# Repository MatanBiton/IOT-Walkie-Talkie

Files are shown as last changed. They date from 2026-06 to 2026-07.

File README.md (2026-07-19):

# Walkie-Talkie Project — Group 14
Group members: Erel Hadad, Sapir Kvetny, Matan Biton  

Advisors: Rami Abu Much, Tom Sofer
## Details about the project

A half-duplex ESP32 walkie-talkie with channel selection through an OLED interface. Audio is transmitted through Firebase Realtime Database in **VoIP mode** and can fall back to **ESP-NOW P2P mode** after repeated upload failures. The system also provides user-availability checks, adjustable audio settings, communication-status feedback, and a companion Flutter application.

Before flashing each ESP32, configure its unique `DEVICE_ID` and `USER_ID`, Wi-Fi settings, and Firebase RTDB URL in `ESP32/app_config.h`.

## Folder description

* `ESP32/`: ESP32 firmware source code.
* `Documentation/`: wiring diagram, Fritzing connection diagram file and basic operating instructions.
* `Unit Tests/`: tests for individual input and output hardware components.
* `assets/`: project poster.

## ESP32 SDK version used in this project

* **ESP32 Arduino Core by Espressif Systems:** `2.0.17`

## Arduino/ESP32 libraries used in this project

* **FirebaseClient by Mobizt** — version **2.2.13** or a compatible 2.2.x release.
* **ESP_SSLClient** — **3.1.3**.
* **Adafruit GFX Library** — **1.12.6**.
* **Adafruit SSD1306** — **2.5.17**.
* **WiFi, Wire, ESP-NOW, I2S, FreeRTOS and mbedTLS** — included with the ESP32 Arduino Core.

## Hardware list

Quantities below are for **one Walkie-Talkie device**.

|  Quantity | Component | Purpose |
| ---: | --- | --- |
| 1 | ESP32 development board | Main controller, Wi-Fi and ESP-NOW communication |
| 1 | INMP441 I2S microphone | Captures voice input |
| 1 | max98357 audio DAC amplifier | Drives the speaker |
| 1 | Speaker | Plays received audio |
| 1 | 128×64 SSD1306 I2C OLED display | Displays channels, status, settings and statistics |
| 3 | Momentary push buttons | PTT, left navigation and right navigation |
| 1 | LED | Indicates recording and pending communication work |
| 1 | LED current-limiting resistor | Protects the status LED |
| 1 | USB cable and suitable USB power source | Programs and powers the ESP32 |
| As needed | Breadboard, perfboard or custom mounting board | Holds and connects the components |
| As needed | Jumper wires / hookup wire | Electrical connections |
| 1 set | 3D-printed enclosure parts | Houses the completed device |

## Connection diagram

| Component | ESP32 connection |
| --- | --- |
| I2S speaker | LRC/WS: GPIO 12, BCLK: GPIO 14, DIN: GPIO 27 |
| I2S microphone  | SD: GPIO 34, SCK/BCLK: GPIO 32, WS: GPIO 33  |
| Main PTT button | GPIO 25 to physical GND |
| Left button | Input: GPIO 4, virtual GND: GPIO 15 |
| Right button | Input: GPIO 19, virtual GND: GPIO 5 |
| SSD1306 OLED | SCL: GPIO 22, SDA: GPIO 23 |
| Status LED | GPIO 26 through a current-limiting resistor  |

The buttons use `INPUT_PULLUP`, so a pressed button reads `LOW`. GPIO 15 and GPIO 5 are configured as outputs and held `LOW` to act as virtual grounds.

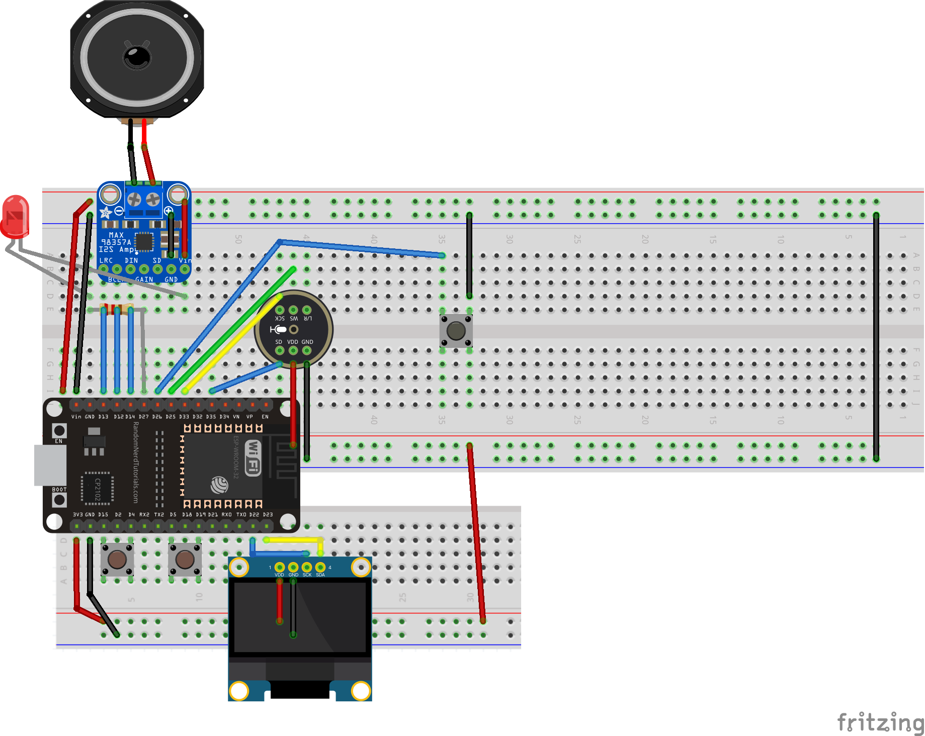
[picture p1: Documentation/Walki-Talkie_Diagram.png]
Connection diagram


## Project Poster

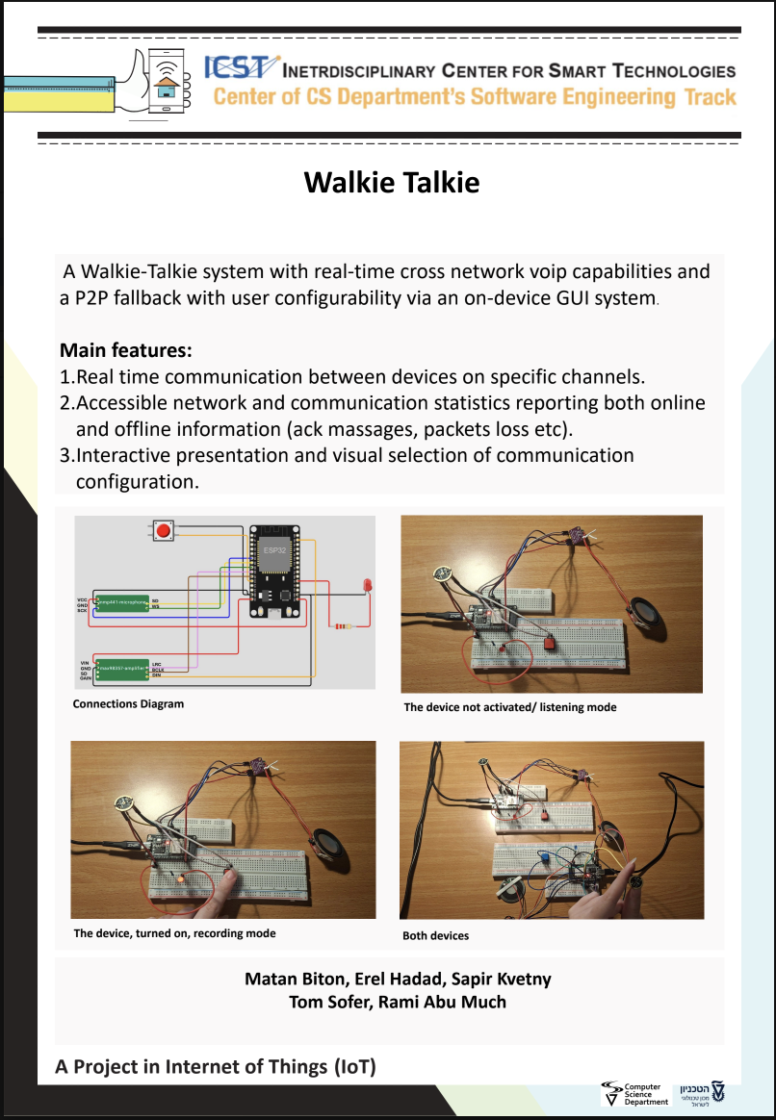
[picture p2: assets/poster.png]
Project poster


---

This project is part of [ICST — The Interdisciplinary Center for Smart Technologies](https://icst.cs.technion.ac.il/), Taub Faculty of Computer Science, Technion.

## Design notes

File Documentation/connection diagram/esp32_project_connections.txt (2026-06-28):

ESP32 Project Hardware Connections
===================================

Current existing connections should remain unchanged.

1. Existing Main Button
-----------------------
ESP32 GPIO14 -> button -> GND

Code note:
- Configure GPIO14 as INPUT_PULLUP.
- Button is active-low:
  pressed = LOW
  released = HIGH

2. Recording LED
----------------
ESP32 GPIO4 -> resistor -> long LED leg / anode
short LED leg / cathode -> GND

Code note:
- Configure GPIO4 as OUTPUT.

3. I2S Microphone
-----------------
Mic VCC / VDD  -> ESP32 3.3V
Mic GND        -> ESP32 GND
Mic SCK / BCLK -> ESP32 GPIO32
Mic WS / LRCLK -> ESP32 GPIO25
Mic SD / DOUT  -> ESP32 GPIO33

4. I2S Speaker Amplifier
------------------------
ESP32 GPIO27 -> amplifier BCLK / BCK
ESP32 GPIO26 -> amplifier LRC / WS
ESP32 GPIO22 -> amplifier DIN / DATA
ESP32 GND    -> amplifier GND
ESP32 5V/VIN -> amplifier VIN / VCC

5. OLED Display - 0.96 inch 128x64 SSD1306
------------------------------------------
Assumed interface: I2C, 4-pin OLED module.

OLED VCC -> ESP32 3.3V
OLED GND -> ESP32 GND
OLED SDA -> ESP32 GPIO21
OLED SCL -> ESP32 GPIO19

6. GUI Button 1 (Left)
--------------------------
ESP32 GPIO18 -> button -> GND

Code note:
- Configure GPIO18 as INPUT_PULLUP.
- Button is active-low:
  pressed = LOW
  released = HIGH

7. GUI Button 2 (rIGHT)
--------------------------
ESP32 GPIO23 -> button -> GND

Code note:
- Configure GPIO23 as INPUT_PULLUP.
- Button is active-low:
  pressed = LOW
  released = HIGH

Final GPIO Usage Summary
========================

GPIO4  - Recording LED
GPIO14 - Existing main button
GPIO18 - GUI button 1
GPIO19 - OLED SCL
GPIO21 - OLED SDA
GPIO22 - I2S speaker amplifier DIN / DATA
GPIO23 - GUI button 2
GPIO25 - I2S microphone WS / LRCLK
GPIO26 - I2S speaker amplifier LRC / WS
GPIO27 - I2S speaker amplifier BCLK / BCK
GPIO32 - I2S microphone SCK / BCLK
GPIO33 - I2S microphone SD / DOUT

Reserved / Avoided Pins
=======================

GPIO22 is not used for OLED SCL because it is already assigned to the speaker amplifier data line.

Avoid GPIO0, GPIO2, GPIO12, and GPIO15 unless necessary, because they may affect ESP32 boot behavior depending on the board and external circuitry.

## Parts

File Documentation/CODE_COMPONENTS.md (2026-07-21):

# Firmware Component Guide
## System flow

`main.ino` coordinates the GUI, PTT state machine, audio capture/playback, Wi-Fi, Firebase RTDB VoIP, and ESP-NOW P2P fallback.

- **VoIP path:** `AudioIO` → `RtdbRequestService` → Firebase RTDB → `RtdbAudioStream` → `AudioIO`.
- **P2P path:** `AudioIO` → `P2pAudio` → `EspNowTransport` → `P2pAudio` → `AudioIO`.
- **Supporting services:** `WifiConnection`, `AvailabilityService`, `RuntimeStatistics`, `Communication`, and `Gui`.

## Entry point and configuration

| File | Role |
|---|---|
| `main.ino` | Main application coordinator. Initializes all modules and FreeRTOS tasks; handles channel changes, PTT sessions, VoIP/P2P selection and fallback, SSE pause/resume, playback queues, LED behavior, GUI events, availability refreshes, NTP synchronization, and deferred statistics persistence. |
| `app_config.h` | Central compile-time configuration: device/user identity, Wi-Fi and Firebase settings, runtime defaults, queue sizes, timeouts, retry policies, RTDB buffering, availability behavior, audio format/settings, P2P thresholds, task parameters, and statistics persistence. Keep local credentials out of version control. |
| `consts.h` | Hardware constants: ESP32 GPIO mapping, OLED dimensions/address, and common button/debounce logic. |

## Audio and communication state

| File | Role |
|---|---|
| `audio_io.h` | Public interface for microphone capture, speaker playback/draining, playback enablement, speaker volume, microphone gain, and noise-gate settings. |
| `audio_io.cpp` | Implements the two I2S devices. Captures mono PCM, applies gain and noise gating, converts mono samples for speaker output, applies volume scaling, manages DMA draining, and supports immediate playback cancellation on communication-blocking screens. |
| `communication_state.h` | Defines the active transport (`VoIP`/`P2P`), communication states, transition API, playback permission, and automatic-P2P-downgrade setting. |
| `communication_state.cpp` | Thread-safe storage and logging for transport changes, state-machine transitions, and the runtime automatic-fallback toggle. |

## Network transports

| File | Role |
|---|---|
| `wifi_connection.h` | Public asynchronous Wi-Fi manager API: connect/status checks, runtime enable/disable, controlled reconnect requests, and connectivity-restored observers. |
| `wifi_connection.cpp` | Runs the Wi-Fi manager task, processes ESP32 Wi-Fi events, performs rate-limited reconnects, logs connection diagnostics, and notifies dependent tasks after connectivity returns. Disabling infrastructure Wi-Fi keeps the STA radio available for ESP-NOW. |
| `esp_now_transport.h` | Shared low-level ESP-NOW interface used by both audio and availability traffic. Defines receive-handler registration and serialized broadcast sending. |
| `esp_now_transport.cpp` | Initializes ESP-NOW and its broadcast peer, dispatches received packets to registered modules, serializes sends, and prioritizes audio by rejecting/deferring availability traffic while P2P audio is active. |
| `p2p_audio.h` | Defines the P2P audio protocol and public API for transport-switch announcements, stream start/audio/end packets, received-packet retrieval, and remote switch requests. |
| `p2p_audio.cpp` | Implements the compact ESP-NOW wire protocol, stream IDs and sequence numbers, packet validation, repeated switch announcements, fixed receive queues, and conversion from wire packets to PCM blocks consumed by the application. |

## Firebase RTDB VoIP

| File | Role |
|---|---|
| `rtdb_request_service.h` | Public RTDB worker API for session start/end, stream start/stop, fixed audio-block acquisition/submission, upload status/counters, abort/reconnect handling, and low-priority presence operations. |
| `rtdb_request_service.cpp` | Sole owner of the Firebase client and TLS connection. Serializes all RTDB work in one task, uploads PCM chunks, writes session metadata, controls the SSE stream, handles retries/timeouts, uses fixed memory pools and queues, drops stale audio under pressure, and schedules presence work only when audio/control traffic is idle. |
| `rtdb_audio_stream.h` | Public listener/parser interface and metadata structure for decoded remote PCM chunks. |
| `rtdb_audio_stream.cpp` | Receives Firebase SSE `put`/`patch` events from the RTDB worker, tracks one active remote talker/session, rejects stale or unrelated chunks, decodes Base64 PCM into caller buffers, and releases stream memory when listening stops. |

## Availability, GUI, and statistics

| File | Role |
|---|---|
| `availability_service.h` | Public API and status types for user availability, refresh state, event-driven polling, optional maintenance leases, and copying cached user status to the GUI. |
| `availability_service.cpp` | Combines server-timestamped RTDB presence leases with on-demand ESP-NOW discovery/replies. Classifies VoIP/P2P evidence as available, stale, or unknown without a dedicated task or periodic full-database polling. |
| `gui.h` | Declares all OLED screens, channel/user/status types, navigation results, communication-blocking rules, and the `AppGui` interface. |
| `gui.cpp` | Implements button handling and SSD1306 rendering for the main menu, channel selection/join screen, user availability, four statistics pages, audio settings, Wi-Fi/P2P settings, and channel-leave/navigation events. |
| `runtime_statistics.h` | Defines the statistics snapshot and recording API for sessions, talk/heard time, transport usage, losses, fallbacks, channel usage, and heard users. |
| `runtime_statistics.cpp` | Maintains thread-safe counters, merges RTDB network counters, calculates P2P diagnostics, and loads/saves selected long-term statistics in ESP32 NVS using deferred, schema-versioned persistence. |

## Ownership summary

- **Hardware access:** `audio_io.*`, `consts.h`, `gui.cpp`.
- **Application orchestration:** `main.ino`, `communication_state.*`.
- **Infrastructure networking:** `wifi_connection.*`, `rtdb_request_service.*`, `rtdb_audio_stream.*`.
- **Local fallback networking:** `esp_now_transport.*`, `p2p_audio.*`.
- **User-facing support:** `gui.*`, `availability_service.*`, `runtime_statistics.*`.

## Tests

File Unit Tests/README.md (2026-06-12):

## This folder contains Validation tests done to check sensors/hardware parts

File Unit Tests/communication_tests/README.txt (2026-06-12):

ESP32 Walkie-Talkie Experiments

This folder contains three successful ESP-NOW communication experiments using two ESP32 boards.

Hardware used:
- Two ESP32 boards with CP2102 USB-serial chips
- Push button
- I2S speaker amplifier + speaker
- I2S microphone
- LED + 220-330 ohm resistor

General button wiring:
GPIO14 -> button -> GND

The button code uses INPUT_PULLUP:
not pressed = HIGH
pressed     = LOW

Recording LED wiring:
GPIO4 -> resistor -> long LED leg
short LED leg -> GND

Experiment 1: Basic ESP-NOW byte communication

Files:
sender.ino
receiver.ino

Goal:
Press button on sender -> send a small packet
Receiver -> print received bytes

Sender hardware:
GPIO14 -> button -> GND

Receiver hardware:
No extra hardware.
Only USB connection for Serial Monitor.

Experiment 2: Fake audio packet + speaker playback

Files:
sender_fake_sound.ino
receiver_with_speaker.ino

Goal:
Sender generates fake audio samples (short pulses) as long as button is pressed.
Receiver receives them and plays them through the speaker.

Sender hardware:
GPIO14 -> button -> GND

Receiver hardware:
I2S speaker amplifier:
ESP32 GPIO27 -> BCLK / BCK
ESP32 GPIO26 -> LRC / WS
ESP32 GPIO22 -> DIN / DATA
ESP32 GND    -> GND
ESP32 5V/VIN -> VIN / VCC

Speaker:
Speaker + -> amplifier +
Speaker - -> amplifier -

Experiment 3: Microphone recording, send, and play

Files:
sender_with_microphone.ino
receiver_mic_to_speaker.ino

Goal:
First button press  -> start recording
Second button press -> stop recording
Auto-stop           -> after 5 seconds
Then sender transmits the recording over ESP-NOW.
Receiver plays the recording through the speaker.

Sender hardware:
Button:
GPIO14 -> button -> GND

Recording LED:
GPIO4 -> resistor -> long LED leg
short LED leg -> GND

I2S microphone:
Mic VCC / VDD  -> 3.3V
Mic GND        -> GND
Mic SCK / BCLK -> GPIO32
Mic WS / LRCLK -> GPIO25
Mic SD / DOUT  -> GPIO33

Receiver hardware:
I2S speaker amplifier:
ESP32 GPIO27 -> BCLK / BCK
ESP32 GPIO26 -> LRC / WS
ESP32 GPIO22 -> DIN / DATA
ESP32 GND    -> GND
ESP32 5V/VIN -> VIN / VCC

Speaker:
Speaker + -> amplifier +
Speaker - -> amplifier -

Important notes:

The receiver MAC address is hardcoded in the sender code:
uint8_t receiverMac[] = {0xF4, 0x65, 0x0B, 0xE9, 0x3B, 0x64};

If using a different receiver ESP, update this MAC address.

The final recording experiment used a lower sample rate than the original mic test to reduce memory usage and packet pressure.

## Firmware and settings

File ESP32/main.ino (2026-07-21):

#include "app_config.h"
#include "availability_service.h"
#include "audio_io.h"
#include "communication_state.h"
#include "consts.h"
#include "gui.h"
#include "p2p_audio.h"
#include "rtdb_audio_stream.h"
#include "rtdb_request_service.h"
#include "runtime_statistics.h"
#include "wifi_connection.h"

#include <esp_system.h>
#include <freertos/FreeRTOS.h>
#include <freertos/queue.h>
#include <freertos/task.h>
#include <string.h>
#include <sys/time.h>
#include <time.h>
#include <esp_heap_caps.h>

namespace {

constexpr uint32_t SSE_TASK_STACK_BYTES = 12288;
constexpr uint8_t SSE_TASK_PRIORITY = 2;
constexpr uint8_t SSE_TASK_CORE = 0;
constexpr uint32_t SSE_IDLE_DELAY_MS = 2;

struct PlaybackBlock {
  int16_t samples[AudioConfig::CHUNK_SAMPLES];
  size_t sampleCount = 0;
  uint32_t sequence = 0;
  // P2P aggregates are consecutive sections of one live stream and therefore
  // skip the per-block DMA drain. VoIP chunks retain the existing behavior.
  bool continuousPlayback = false;
  char sessionId[64] = {0};
  char deviceId[48] = {0};
};

static_assert(
    P2pAudioConfig::PLAYBACK_SAMPLES_PER_BLOCK <= AudioConfig::CHUNK_SAMPLES,
    "P2P playback aggregate exceeds PlaybackBlock capacity");

PlaybackBlock playbackBlocks[PlaybackConfig::BLOCK_COUNT];
QueueHandle_t playbackFreeQueue = nullptr;
QueueHandle_t playbackReadyQueue = nullptr;
TaskHandle_t playbackTaskHandle = nullptr;
TaskHandle_t sseTaskHandle = nullptr;
TaskHandle_t communicationTaskHandle = nullptr;
TaskHandle_t activityLedTaskHandle = nullptr;

portMUX_TYPE playbackMux = portMUX_INITIALIZER_UNLOCKED;
portMUX_TYPE channelMux = portMUX_INITIALIZER_UNLOCKED;
bool playbackInFlight = false;
constexpr uint8_t NO_CHANNEL = 0;
uint8_t listeningChannel = NO_CHANNEL;
uint8_t pendingChannel = NO_CHANNEL;
bool channelChangePending = false;
portMUX_TYPE sseControlMux = portMUX_INITIALIZER_UNLOCKED;
bool ssePauseRequested = false;
bool ssePauseAcknowledged = false;

portMUX_TYPE guiPttMux = portMUX_INITIALIZER_UNLOCKED;
bool guiPttCaptureActive = false;
bool guiPttSuppressedUntilRelease = false;
bool guiCommunicationBlocked = false;

enum class ActivityLedMode : uint8_t {
  Off,
  Recording,
  Busy,
};

portMUX_TYPE activityLedMux = portMUX_INITIALIZER_UNLOCKED;
ActivityLedMode currentActivityLedMode = ActivityLedMode::Off;

AvailabilityService::UserStatus availabilitySnapshot[AvailabilityConfig::USER_COUNT];
int16_t droppedMicBuffer[AudioConfig::CHUNK_SAMPLES];
int16_t p2pMicBuffer[P2pAudioConfig::SAMPLES_PER_PACKET];

portMUX_TYPE transportSessionMux = portMUX_INITIALIZER_UNLOCKED;
uint32_t channelFailureBaseline = 0;

void setGuiPttCaptureActive(bool active) {
  portENTER_CRITICAL(&guiPttMux);
  guiPttCaptureActive = active;
  portEXIT_CRITICAL(&guiPttMux);
}

void setGuiCommunicationBlocked(bool blocked) {
  bool changed = false;
  portENTER_CRITICAL(&guiPttMux);
  changed = guiCommunicationBlocked != blocked;
  guiCommunicationBlocked = blocked;
  portEXIT_CRITICAL(&guiPttMux);

  if (changed) {
    Serial.printf(
        "[GUI] communication_blocked=%s screen=statistics\n",
        blocked ? "true" : "false");
  }
  AudioIO::setSpeakerPlaybackEnabled(!blocked);
}

bool isGuiCommunicationBlocked() {
  portENTER_CRITICAL(&guiPttMux);
  const bool blocked = guiCommunicationBlocked;
  portEXIT_CRITICAL(&guiPttMux);
  return blocked;
}

void suppressPttUntilRelease() {
  portENTER_CRITICAL(&guiPttMux);
  guiPttSuppressedUntilRelease = true;
  portEXIT_CRITICAL(&guiPttMux);
}

void clearPttReleaseSuppression() {
  portENTER_CRITICAL(&guiPttMux);
  guiPttSuppressedUntilRelease = false;
  portEXIT_CRITICAL(&guiPttMux);
}

void readGuiPttState(bool& captureActive, bool& suppressedUntilRelease) {
  portENTER_CRITICAL(&guiPttMux);
  captureActive = guiPttCaptureActive;
  suppressedUntilRelease = guiPttSuppressedUntilRelease;
  portEXIT_CRITICAL(&guiPttMux);
}

const char* activityLedModeName(ActivityLedMode mode) {
  switch (mode) {
    case ActivityLedMode::Off: return "off";
    case ActivityLedMode::Recording: return "recording_solid";
    case ActivityLedMode::Busy: return "busy_blink";
    default: return "unknown";
  }
}

ActivityLedMode activityLedMode() {
  portENTER_CRITICAL(&activityLedMux);
  const ActivityLedMode mode = currentActivityLedMode;
  portEXIT_CRITICAL(&activityLedMux);
  return mode;
}

void setActivityLedMode(ActivityLedMode mode) {
  bool changed = false;
  ActivityLedMode previous = ActivityLedMode::Off;

  portENTER_CRITICAL(&activityLedMux);
  previous = currentActivityLedMode;
  if (previous != mode) {
    currentActivityLedMode = mode;
    changed = true;
  }
  portEXIT_CRITICAL(&activityLedMux);

  if (!changed) {
    return;
  }

  Serial.printf(
      "[LED] old=%s new=%s\n",
      activityLedModeName(previous),
      activityLedModeName(mode));

  if (activityLedTaskHandle != nullptr) {
    xTaskNotifyGive(activityLedTaskHandle);
  }
}

void activityLedTask(void*) {
  ActivityLedMode appliedMode = ActivityLedMode::Off;
  bool initialized = false;
  bool ledOn = false;

  for (;;) {
    const ActivityLedMode requestedMode = activityLedMode();
    if (!initialized || requestedMode != appliedMode) {
      appliedMode = requestedMode;
      initialized = true;

      // Enter the busy state with the LED on, then alternate at the configured
      // interval. Recording remains continuously lit and idle remains off.
      ledOn = appliedMode != ActivityLedMode::Off;
      digitalWrite(Pins::RECORDING_LED, ledOn ? HIGH : LOW);
    }

    const TickType_t waitTicks =
        appliedMode == ActivityLedMode::Busy
            ? pdMS_TO_TICKS(ActivityLedConfig::BUSY_BLINK_INTERVAL_MS)
            : portMAX_DELAY;

    const uint32_t notificationCount = ulTaskNotifyTake(pdTRUE, waitTicks);
    if (notificationCount == 0 && appliedMode == ActivityLedMode::Busy) {
      ledOn = !ledOn;
      digitalWrite(Pins::RECORDING_LED, ledOn ? HIGH : LOW);
    }
  }
}

class DebouncedPtt {
 public:
  void begin() {
    lastRawPressed_ = rawPressed();
    stablePressed_ = lastRawPressed_;
    lastChangeMs_ = millis();
  }

  void update() {
    const bool raw = rawPressed();
    const uint32_t now = millis();
    if (raw != lastRawPressed_) {
      lastRawPressed_ = raw;
      lastChangeMs_ = now;
    }
    if (raw != stablePressed_ && (now - lastChangeMs_) >= ButtonLogic::DEBOUNCE_MS) {
      stablePressed_ = raw;
    }
  }

  bool pressed() const { return stablePressed_; }
  bool rawPressed() const { return digitalRead(Pins::MAIN_BUTTON) == ButtonLogic::PRESSED; }

 private:
  bool lastRawPressed_ = false;
  bool stablePressed_ = false;
  uint32_t lastChangeMs_ = 0;
};

void wakeTaskOnWifiRestore(void* context) {
  TaskHandle_t task = static_cast<TaskHandle_t>(context);
  if (task != nullptr) {
    xTaskNotifyGive(task);
  }
}

bool isSsePauseRequested() {
  portENTER_CRITICAL(&sseControlMux);
  const bool requested = ssePauseRequested;
  portEXIT_CRITICAL(&sseControlMux);
  return requested;
}

void setSsePauseAcknowledged(bool acknowledged) {
  portENTER_CRITICAL(&sseControlMux);
  ssePauseAcknowledged = acknowledged;
  portEXIT_CRITICAL(&sseControlMux);
}

bool isSsePauseAcknowledged() {
  portENTER_CRITICAL(&sseControlMux);
  const bool acknowledged = ssePauseAcknowledged;
  portEXIT_CRITICAL(&sseControlMux);
  return acknowledged;
}

bool pauseSseForRtdbRequests(uint32_t timeoutMs) {
  portENTER_CRITICAL(&sseControlMux);
  ssePauseRequested = true;
  ssePauseAcknowledged = false;
  portEXIT_CRITICAL(&sseControlMux);

  if (sseTaskHandle != nullptr) {
    xTaskNotifyGive(sseTaskHandle);
  }

  const uint32_t startedAtMs = millis();

  while (!isSsePauseAcknowledged()) {
    if ((millis() - startedAtMs) >= timeoutMs) {
      Serial.printf(
          "[RTDB][STREAM] pause_timeout timeoutMs=%lu listening=%s\n",
          static_cast<unsigned long>(timeoutMs),
          RtdbAudioStream::isListening() ? "true" : "false");
      return false;
    }

    vTaskDelay(pdMS_TO_TICKS(5));
  }

  // Give the TLS allocator a brief opportunity to release its buffers.
  vTaskDelay(pdMS_TO_TICKS(20));

  Serial.printf(
      "[RTDB][STREAM] paused_for_requests freeHeap=%lu largestBlock=%lu\n",
      static_cast<unsigned long>(ESP.getFreeHeap()),
      static_cast<unsigned long>(
          heap_caps_get_largest_free_block(MALLOC_CAP_8BIT)));

  return true;
}

void resumeSseAfterRtdbRequests() {
  portENTER_CRITICAL(&sseControlMux);
  ssePauseRequested = false;
  ssePauseAcknowledged = false;
  portEXIT_CRITICAL(&sseControlMux);

  Serial.println("[RTDB][STREAM] resume_requested");

  if (sseTaskHandle != nullptr) {
    xTaskNotifyGive(sseTaskHandle);
  }
}

uint32_t flushPlaybackQueue(const char* reason);

uint8_t currentListeningChannel() {
  portENTER_CRITICAL(&channelMux);
  const uint8_t channel = listeningChannel;
  portEXIT_CRITICAL(&channelMux);
  return channel;
}

uint8_t userNumberFromDeviceId(const char* deviceId) {
  if (deviceId == nullptr) {
    return 0;
  }
  const size_t length = strlen(deviceId);
  if (length < 2) {
    return 0;
  }
  const char tens = deviceId[length - 2];
  const char ones = deviceId[length - 1];
  if (tens < '0' || tens > '9' || ones < '0' || ones > '9') {
    return 0;
  }
  const uint8_t userNumber =
      static_cast<uint8_t>((tens - '0') * 10 + (ones - '0'));
  return userNumber >= 1 && userNumber <= AvailabilityConfig::USER_COUNT
             ? userNumber
             : 0;
}

void syncRuntimeStatisticsNetworkCounters() {
  RuntimeStatistics::setVoipNetworkCounters(
      RtdbRequestService::totalAudioUploadFailures(),
      RtdbRequestService::totalDiscardedAudioSamples());
}

uint32_t failedUploadsInJoinedChannel() {
  const uint32_t total = RtdbRequestService::totalAudioUploadFailures();
  portENTER_CRITICAL(&transportSessionMux);
  const uint32_t baseline = channelFailureBaseline;
  portEXIT_CRITICAL(&transportSessionMux);
  return total - baseline;
}

bool voipFailureLimitExceeded() {
  if (!Communication::automaticP2pDowngradeEnabled()) {
    return false;
  }

  const uint32_t limit =
      P2pAudioConfig::VOIP_FAILED_UPLOAD_ATTEMPT_LIMIT;
  return limit == 0 || failedUploadsInJoinedChannel() > limit;
}

void resetChannelTransport(uint8_t channel) {
  const uint32_t baseline =
      RtdbRequestService::totalAudioUploadFailures();
  portENTER_CRITICAL(&transportSessionMux);
  channelFailureBaseline = baseline;
  portEXIT_CRITICAL(&transportSessionMux);

  P2pAudio::clearReceiveQueue();
  const bool wifiEnabled = WifiConnection::isEnabled();
  const bool automaticP2pDowngrade =
      Communication::automaticP2pDowngradeEnabled();
  const bool immediateP2p =
      !wifiEnabled ||
      (automaticP2pDowngrade &&
       P2pAudioConfig::VOIP_FAILED_UPLOAD_ATTEMPT_LIMIT == 0);
  const Communication::Transport initialTransport =
      immediateP2p ? Communication::Transport::P2p
                   : Communication::Transport::Voip;
  Communication::setTransport(
      initialTransport,
      channel == NO_CHANNEL ? "channel_left" : "channel_joined");

  if (channel != NO_CHANNEL &&
      initialTransport == Communication::Transport::P2p) {
    // Explicit Wi-Fi disable and zero-threshold automatic fallback both start
    // the joined channel in P2P. Announce so a peer still on VoIP follows us.
    P2pAudio::announceSwitch(channel, 0);
  }

  Serial.printf(
      "[TRANSPORT] channel=%u failureBaseline=%lu limit=%lu wifi=%s autoP2p=%s initial=%s\n",
      static_cast<unsigned int>(channel),
      static_cast<unsigned long>(baseline),
      static_cast<unsigned long>(
          P2pAudioConfig::VOIP_FAILED_UPLOAD_ATTEMPT_LIMIT),
      wifiEnabled ? "enabled" : "disabled",
      automaticP2pDowngrade ? "enabled" : "disabled",
      Communication::transportName(initialTransport));

  if (sseTaskHandle != nullptr) {
    xTaskNotifyGive(sseTaskHandle);
  }
}

bool activateP2pTransport(const char* reason, bool announce) {
  const uint8_t channel = currentListeningChannel();
  if (channel == NO_CHANNEL) {
    return false;
  }

  const uint32_t failures = failedUploadsInJoinedChannel();
  const bool changed =
      Communication::transport() != Communication::Transport::P2p;
  Communication::setTransport(Communication::Transport::P2p, reason);

  // Stop admitting new RTDB audio immediately. Any request already inside the
  // bounded Firebase call is allowed to return, while queued stale PCM is freed.
  RtdbRequestService::setRecordingActive(false);
  RtdbRequestService::requestAudioUploadAbort("transport_switched_to_p2p");
  RtdbRequestService::discardPendingAudio("transport_switched_to_p2p");

  if (announce) {
    P2pAudio::announceSwitch(channel, failures);
  }

  if (sseTaskHandle != nullptr) {
    xTaskNotifyGive(sseTaskHandle);
  }
  if (communicationTaskHandle != nullptr) {
    xTaskNotifyGive(communicationTaskHandle);
  }

  if (changed) {
    RuntimeStatistics::recordFallback();
    Serial.printf(
        "[TRANSPORT] fallback channel=%u failures=%lu limit=%lu announce=%s\n",
        static_cast<unsigned int>(channel),
        static_cast<unsigned long>(failures),
        static_cast<unsigned long>(
            P2pAudioConfig::VOIP_FAILED_UPLOAD_ATTEMPT_LIMIT),
        announce ? "true" : "false");
  }
  return true;
}

void processRemoteP2pSwitchRequest() {
  P2pAudio::SwitchRequest request;
  while (P2pAudio::takeSwitchRequest(request)) {
    const uint8_t channel = currentListeningChannel();
    if (channel == NO_CHANNEL || request.logicalChannel != channel) {
      Serial.printf(
          "[P2P] switch_ignored sourceUser=%u packetChannel=%u joinedChannel=%u\n",
          static_cast<unsigned int>(request.senderUser),
          static_cast<unsigned int>(request.logicalChannel),
          static_cast<unsigned int>(channel));
      continue;
    }

    if (Communication::transport() == Communication::Transport::P2p) {
      continue;
    }

    Serial.printf(
        "[P2P] remote_switch sourceUser=%u channel=%u reportedFailures=%lu\n",
        static_cast<unsigned int>(request.senderUser),
        static_cast<unsigned int>(request.logicalChannel),
        static_cast<unsigned long>(request.failedUploads));
    activateP2pTransport("peer_requested_p2p", false);
  }
}

void syncCommunicationMethodToGui() {
  static Communication::Transport lastShown =
      static_cast<Communication::Transport>(0xff);
  const Communication::Transport current = Communication::transport();
  if (current == lastShown) {
    return;
  }
  lastShown = current;
  Gui::appGui.setCommunicationMethod(
      current == Communication::Transport::P2p
          ? Gui::CommunicationMethod::P2p
          : Gui::CommunicationMethod::Voip);
}

void requestLogicalChannel(uint8_t channel) {
  // Channel 0 is the explicit "not joined" state.
  if (channel > Gui::CHANNEL_COUNT) {
    return;
  }
  portENTER_CRITICAL(&channelMux);
  pendingChannel = channel;
  channelChangePending = true;
  portEXIT_CRITICAL(&channelMux);
  if (channel == NO_CHANNEL) {
    Serial.printf(
        "[CHANNEL] requested=none state=%s\n",
        Communication::stateName(Communication::state()));
  } else {
    Serial.printf(
        "[CHANNEL] requested=%u state=%s\n",
        static_cast<unsigned int>(channel),
        Communication::stateName(Communication::state()));
  }
  if (communicationTaskHandle != nullptr) {
    xTaskNotifyGive(communicationTaskHandle);
  }
}

void applyPendingLogicalChannel() {
  bool changed = false;
  uint8_t channel = NO_CHANNEL;
  uint8_t previousChannel = NO_CHANNEL;
  portENTER_CRITICAL(&channelMux);
  if (channelChangePending) {
    previousChannel = listeningChannel;
    listeningChannel = pendingChannel;
    channel = listeningChannel;
    channelChangePending = false;
    changed = true;
  }
  portEXIT_CRITICAL(&channelMux);
  if (!changed) {
    return;
  }

  resetChannelTransport(channel);

  if (channel == NO_CHANNEL) {
    const uint32_t discarded = flushPlaybackQueue("left_channel");
    Serial.printf(
        "[CHANNEL] left previous=%u discardedPlayback=%lu freeHeap=%lu largestBlock=%lu\n",
        static_cast<unsigned int>(previousChannel),
        static_cast<unsigned long>(discarded),
        static_cast<unsigned long>(ESP.getFreeHeap()),
        static_cast<unsigned long>(
            heap_caps_get_largest_free_block(MALLOC_CAP_8BIT)));
  } else {
    Serial.printf("[CHANNEL] active=%u\n", static_cast<unsigned int>(channel));
  }

  // Leaving a joined channel (including a direct switch to another channel)
  // requests a save. The actual NVS write is performed by the Arduino loop,
  // not by this communication-task path.
  if (previousChannel != NO_CHANNEL && previousChannel != channel) {
    RuntimeStatistics::requestPersistenceSave();
  }

  if (sseTaskHandle != nullptr) {
    xTaskNotifyGive(sseTaskHandle);
  }
}

Gui::AvailabilityIndicator toGuiAvailabilityIndicator(
    AvailabilityService::EvidenceState state) {
  switch (state) {
    case AvailabilityService::EvidenceState::Available:
      return Gui::AvailabilityIndicator::Available;
    case AvailabilityService::EvidenceState::Stale:
      return Gui::AvailabilityIndicator::Stale;
    case AvailabilityService::EvidenceState::Unknown:
    default:
      return Gui::AvailabilityIndicator::Unknown;
  }
}

Gui::AvailabilityRefreshIndicator toGuiRefreshIndicator(
    AvailabilityService::RefreshState state) {
  switch (state) {
    case AvailabilityService::RefreshState::Refreshing:
      return Gui::AvailabilityRefreshIndicator::Refreshing;
    case AvailabilityService::RefreshState::Complete:
      return Gui::AvailabilityRefreshIndicator::Complete;
    case AvailabilityService::RefreshState::Failed:
      return Gui::AvailabilityRefreshIndicator::Failed;
    case AvailabilityService::RefreshState::Idle:
    default:
      return Gui::AvailabilityRefreshIndicator::Idle;
  }
}

void syncAvailabilityToGui() {
  static uint32_t lastRefreshMs = 0;
  const uint32_t now = millis();
  if ((now - lastRefreshMs) < AvailabilityConfig::GUI_REFRESH_MS) {
    return;
  }
  lastRefreshMs = now;

  const size_t count = AvailabilityService::copyUserStatuses(
      availabilitySnapshot,
      AvailabilityConfig::USER_COUNT);
  for (size_t index = 0; index < count; ++index) {
    Gui::appGui.setUserStatus(
        availabilitySnapshot[index].userNumber,
        toGuiAvailabilityIndicator(availabilitySnapshot[index].voip),
        toGuiAvailabilityIndicator(availabilitySnapshot[index].p2p),
        availabilitySnapshot[index].voipAgeSeconds,
        availabilitySnapshot[index].p2pAgeSeconds);
  }
  Gui::appGui.setAvailabilityRefreshIndicator(
      toGuiRefreshIndicator(AvailabilityService::refreshState()));
}

void maybeRunAvailabilityMaintenance() {
  const uint8_t channel = currentListeningChannel();
  const bool communicationBusy = Communication::isTransmitting();
  if (!AvailabilityService::maintenanceLeaseDue(channel, communicationBusy) ||
      Communication::transport() != Communication::Transport::Voip ||
      Communication::state() != Communication::State::Listening) {
    return;
  }

  Serial.println("[Availability][MAINTENANCE] pausing SSE for lease");
  if (!pauseSseForRtdbRequests(CommunicationConfig::SSE_PAUSE_TIMEOUT_MS)) {
    Serial.println("[Availability][MAINTENANCE] SSE pause failed");
    resumeSseAfterRtdbRequests();
    return;
  }

  const bool success = AvailabilityService::performMaintenanceLeaseSync(
      AvailabilityConfig::SSE_MAINTENANCE_OPERATION_TIMEOUT_MS);
  Serial.printf(
      "[Availability][MAINTENANCE] leaseSuccess=%s\n",
      success ? "true" : "false");
  resumeSseAfterRtdbRequests();
}

void handleGuiResult(const Gui::UpdateResult& result) {
  if (result.consumedPttNavigation) {
    suppressPttUntilRelease();
  }
  if (result.hasSelection) {
    Serial.printf(
        "[GUI] selectedScreen=%u\n",
        static_cast<unsigned int>(result.selectedScreen));
  }
  if (result.availabilityRefreshRequested && AvailabilityConfig::ENABLED) {
    AvailabilityService::requestRefresh();
  }
  if (result.availabilityScreenClosed && AvailabilityConfig::ENABLED) {
    AvailabilityService::cancelRefresh();
  }
  if (result.hasChannelLeave) {
    Serial.println("[GUI] leave_channel");
    requestLogicalChannel(NO_CHANNEL);
  } else if (result.hasChannelSelection) {
    requestLogicalChannel(result.selectedChannel);
  }
}

bool isPlaybackInFlight() {
  portENTER_CRITICAL(&playbackMux);
  const bool active = playbackInFlight;
  portEXIT_CRITICAL(&playbackMux);
  return active;
}
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
void loop() {
  processRemoteP2pSwitchRequest();
  syncCommunicationMethodToGui();
  syncRuntimeStatisticsNetworkCounters();

  // NVS writes are deferred until the local audio path is idle. This avoids a
  // periodic flash operation competing with microphone capture, upload drain,
  // or speaker playback. A due/forced save remains pending until this is safe.
  const bool playbackQueued =
      playbackReadyQueue != nullptr &&
      uxQueueMessagesWaiting(playbackReadyQueue) > 0;
  if (!Communication::isTransmitting() &&
      !isPlaybackInFlight() &&
      !playbackQueued) {
    RuntimeStatistics::maintainPersistence();
  }
  setGuiCommunicationBlocked(Gui::appGui.blocksCommunication());
  setGuiPttCaptureActive(Gui::appGui.consumesPttForNavigation());
  const Gui::UpdateResult guiResult = Gui::appGui.update();
  handleGuiResult(guiResult);
  setGuiCommunicationBlocked(Gui::appGui.blocksCommunication());
  setGuiPttCaptureActive(Gui::appGui.consumesPttForNavigation());
  RtdbAudioStream::loopMaintenance();
  if (AvailabilityConfig::ENABLED) {
    AvailabilityService::poll(
        currentListeningChannel(),
        Communication::isTransmitting(),
        Communication::transport() == Communication::Transport::P2p ? 1 : 0);
    syncAvailabilityToGui();
    maintainTimeSynchronization();
    maybeRunAvailabilityMaintenance();
  }
  delay(5);
}

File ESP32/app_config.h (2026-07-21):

#pragma once

#include <Arduino.h>

namespace AppConfig {

constexpr uint8_t DEFAULT_CHANNEL = 1;
constexpr const char* ROOM_ID = "room1";
constexpr const char* DEVICE_ID = "esp32-01";

// Logical project user id. Compile/upload the same code to each ESP after
// changing only this value and DEVICE_ID, for example: "01" ... "05".
constexpr const char* USER_ID = "01";

}  // namespace AppConfig

namespace StatisticsConfig {

// Persistent statistics are written to the ESP32 NVS partition. The live
// network-diagnostics page (SSID, RSSI, P2P TX reject, and P2P RX loss) remains
// current-boot only.
constexpr bool PERSISTENCE_ENABLED = true;
constexpr char NVS_NAMESPACE[] = "run_stats";
constexpr uint8_t SCHEMA_VERSION = 1;

// Dirty statistics are saved at most once per this interval. Leaving or
// switching away from a joined channel requests an immediate save on the main
// loop, without performing flash I/O inside the communication/audio tasks.
constexpr uint32_t SAVE_INTERVAL_MS = 60UL * 1000UL;
constexpr uint32_t SAVE_FAILURE_RETRY_MS = 5000;
constexpr bool LOG_PERSISTENCE = true;

static_assert(sizeof(NVS_NAMESPACE) - 1 <= 15,
              "NVS namespace names are limited to 15 characters");
static_assert(SAVE_INTERVAL_MS >= 1000,
              "Statistics save interval should be at least one second");

}  // namespace StatisticsConfig

namespace WifiConfig {

// Fill locally before uploading. Do not commit real Wi-Fi credentials.
constexpr const char* SSID = "GalaxyA31948B";
constexpr const char* PASSWORD = "enxu9794";
constexpr unsigned int WIFI_CHANNEL = 1;

constexpr unsigned long CONNECT_TIMEOUT_MS = 20000;
constexpr unsigned long RECONNECT_INTERVAL_MS = 5000;

}  // namespace WifiConfig

namespace RuntimeSettingsConfig {

// Runtime-only defaults for the second OLED settings page. Disabling Wi-Fi
// stops infrastructure connection/reconnection while leaving the STA radio
// active for ESP-NOW. Automatic P2P downgrade controls locally initiated
// fallback after failed VoIP uploads; explicit Wi-Fi disable and peer switch
// coordination can still select P2P.
constexpr bool WIFI_ENABLED_DEFAULT = true;
constexpr bool AUTOMATIC_P2P_DOWNGRADE_DEFAULT = true;

}  // namespace RuntimeSettingsConfig

namespace FirebaseConfig {

// Keep the URL without a trailing slash.
// This patch assumes permissive RTDB rules for the demo, so no Firebase Auth,
// API key, email, or password are used.
constexpr const char* DATABASE_URL =
    "https://walki-talkie-37ed3-default-rtdb.europe-west1.firebasedatabase.app";

}  // namespace FirebaseConfig



namespace FirebaseClientConfig {

// The project deliberately compiles only RTDB support and uses NoAuth.
// FIREBASE_ASYNC_QUEUE_LIMIT is set to one in rtdb_request_service.cpp so the
// library never retains multiple 4.4 KB audio payloads.
constexpr uint32_t INITIALIZE_TIMEOUT_MS = 5000;
constexpr uint32_t STREAM_STOP_TIMEOUT_MS = 4500;
constexpr uint32_t STREAM_START_TIMEOUT_MS = 2500;
constexpr uint32_t SYNC_SEND_TIMEOUT_SECONDS = 5;
constexpr uint32_t SYNC_READ_TIMEOUT_SECONDS = 5;
constexpr uint32_t SESSION_TIMEOUT_SECONDS = 180;
constexpr unsigned long TLS_HANDSHAKE_TIMEOUT_SECONDS = 4;

}  // namespace FirebaseClientConfig

namespace AvailabilityConfig {

constexpr bool ENABLED = true;
constexpr uint8_t USER_COUNT = 5;
constexpr uint8_t SCHEMA_VERSION = 1;

// Compact event-driven presence tree. Firebase creates this path on the first
// successful write; no periodic full-tree polling is performed.
constexpr const char* RTDB_USERS_PATH = "/presence/users";
constexpr size_t LEASE_PAYLOAD_BUFFER_BYTES = 256;

// V:ON means a server-timestamped lease is no older than this threshold.
// Abrupt power loss can therefore remain visible for at most this interval.
constexpr uint32_t VOIP_LEASE_FRESH_MS = 5UL * 60UL * 1000UL;
constexpr uint32_t LEASE_MAINTENANCE_INTERVAL_MS = 4UL * 60UL * 1000UL;
constexpr uint32_t LEASE_REQUEST_VALID_MS = 15000;
constexpr uint32_t USERS_READ_REQUEST_VALID_MS = 15000;
// Failed background lease writes are retried only after this quiet interval.
// Manual View Users refreshes do not wait for this backoff.
constexpr uint32_t LEASE_FAILURE_RETRY_MS = 30000;

// Optional stronger presence. When enabled, an idle VoIP listener briefly
// pauses SSE at the maintenance interval, writes one lease, then reconnects.
// Disabled by default because the bounded pause is a real listening gap.
constexpr bool ENABLE_SSE_MAINTENANCE_LEASE = false;
constexpr uint32_t SSE_MAINTENANCE_OPERATION_TIMEOUT_MS = 12000;
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

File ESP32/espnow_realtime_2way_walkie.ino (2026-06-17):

#include <Arduino.h>
#include <WiFi.h>
#include <esp_now.h>
#include <esp_wifi.h>
#include <driver/i2s.h>
#include <esp_err.h>

#if __has_include(<esp_arduino_version.h>)
  #include <esp_arduino_version.h>
#endif
#ifndef ESP_ARDUINO_VERSION_MAJOR
  #define ESP_ARDUINO_VERSION_MAJOR 2
#endif

// =====================================================
// ESP-NOW REAL-TIME TWO-WAY PUSH-TO-TALK WALKIE-TALKIE
//
// Flash this same sketch to BOTH ESP32 boards.
// On each board, set peerMac[] to the OTHER ESP32's WiFi STA MAC.
//
// Behavior:
//   Hold button  -> stream microphone audio to the peer in real time
//   Release      -> stop transmitting
//   Not pressed  -> receive and play peer audio
//
// Assumption: both boards do not press the transmit button at the same time.
// Transport: ESP-NOW only. No WiFi router, no UDP.
// =====================================================

// ---------------- ESP-NOW settings ----------------
// Both ESPs must use the same ESP-NOW channel.
#define ESPNOW_CHANNEL              1

// Replace this on EACH board with the OTHER board's MAC address.
// Example below is the receiver MAC from your previous sender sketch.
uint8_t peerMac[] = {0xF4, 0x65, 0x0B, 0xE9, 0x3B, 0x64};

// Set to 1 only if you want to avoid configuring peer MACs.
// Unicast peer MACs are preferred because send callbacks can report delivery status.
#define USE_BROADCAST_PEER          1
uint8_t broadcastMac[] = {0xff, 0xff, 0xff, 0xff, 0xff, 0xff};

// ---------------- Audio settings ----------------
// 8 kHz keeps ESP-NOW bandwidth low and matches your working sketches.
#define SAMPLE_RATE                 8000
#define AUDIO_SAMPLES_PER_PACKET    100       // 100 samples = 12.5 ms at 8 kHz
#define MIC_READ_SAMPLES            AUDIO_SAMPLES_PER_PACKET

// Your working mic code used raw >> 12 and gain 3 after DC removal.
#define MIC_SHIFT                   12
#define MIC_GAIN                    3
#define SPEAKER_GAIN                1

// Queue depth trades latency vs resilience to brief WiFi jitter.
// 12 packets ~= 150 ms max queue at 8 kHz. Lower = less latency; higher = fewer drops.
#define RX_QUEUE_LEN                12

// ---------------- Button + LED ----------------
#define BUTTON_PIN                  GPIO_NUM_14    // active LOW, INPUT_PULLUP
#define TX_LED_PIN                  GPIO_NUM_4
#define BUTTON_DEBOUNCE_MS          45

// ---------------- I2S microphone pins ----------------
// Same as your working sender_with_microphone.ino
#define I2S_MIC_PORT                I2S_NUM_0
#define I2S_MIC_CHANNEL             I2S_CHANNEL_FMT_ONLY_RIGHT
#define I2S_MIC_BCLK                GPIO_NUM_32
#define I2S_MIC_WS                  GPIO_NUM_25
#define I2S_MIC_SD                  GPIO_NUM_33

// ---------------- I2S speaker pins ----------------
// Same as your working receiver_mic_to_speaker.ino
#define I2S_SPK_PORT                I2S_NUM_1
#define I2S_SPK_BCLK                GPIO_NUM_27
#define I2S_SPK_WS                  GPIO_NUM_26
#define I2S_SPK_SD                  GPIO_NUM_22

// ---------------- Packet format ----------------
// Packet size: 2 + 1 + 1 + 4 + 2 + 200 = 210 bytes, below the classic ESP-NOW 250-byte payload limit.
static const uint16_t PACKET_MAGIC = 0xB17A;

// Use a different stream id when a new push-to-talk burst starts.
// This helps the receiver reset sequence tracking between bursts.
enum PacketType : uint8_t {
  PACKET_START = 1,
  PACKET_AUDIO = 2,
  PACKET_END   = 3
};

typedef struct __attribute__((packed)) {
  uint16_t magic;
  uint8_t type;
  uint8_t streamId;
  uint32_t seq;
  uint16_t sampleCount;
  int16_t samples[AUDIO_SAMPLES_PER_PACKET];
} AudioPacket;

static_assert(sizeof(AudioPacket) <= 250, "AudioPacket is too large for classic ESP-NOW payloads");

// ---------------- Globals ----------------
QueueHandle_t rxQueue = nullptr;

static int32_t micRaw[MIC_READ_SAMPLES];
static int16_t stereoBuffer[AUDIO_SAMPLES_PER_PACKET * 2];

volatile bool isTransmitting = false;
bool remoteStreamActive = false;

uint8_t streamId = 0;
uint32_t txSeq = 0;
int32_t dcEstimate = 0;

uint32_t txPacketsQueued = 0;
uint32_t txSendErrors = 0;
uint32_t txSendOkCallbacks = 0;
uint32_t txSendFailCallbacks = 0;

uint32_t rxPacketsQueued = 0;
uint32_t rxPacketsPlayed = 0;
uint32_t rxQueueDropped = 0;
uint32_t rxBadPackets = 0;
uint32_t rxMissedSeq = 0;
uint32_t rxLastSeq = 0;
uint8_t rxLastStreamId = 0;
bool rxHaveLastSeq = false;

bool lastRawPressed = false;
bool stablePressed = false;
uint32_t lastButtonChangeMs = 0;

static int16_t clampToInt16(int32_t value) {
  if (value > 32767) return 32767;
  if (value < -32768) return -32768;
  return (int16_t)value;
}

void printErr(const char *label, esp_err_t err) {
  if (err == ESP_OK) {
    Serial.printf("[OK]   %s\n", label);
  } else {
    Serial.printf("[FAIL] %s: %d / %s\n", label, err, esp_err_to_name(err));
  }
}

void printMac(const uint8_t *mac) {
  Serial.printf("%02X:%02X:%02X:%02X:%02X:%02X",
                mac[0], mac[1], mac[2], mac[3], mac[4], mac[5]);
}
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

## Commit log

2026-06-08 Change I2S microphone channel and pin assignments
2026-06-28 Uploaded connections wiring for hardware
2026-07-03 display gui 2 buttons example
2026-07-11 Add Wi-Fi connection test for ESP32
2026-07-19 Added Fritzing Diagram
    [Walki-Talkie.fzz]
